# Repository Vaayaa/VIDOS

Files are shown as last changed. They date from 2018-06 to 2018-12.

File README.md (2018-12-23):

# VIDOS: Shader Based Video Synthesizer

VidBoi 1
## Overview

The VIDOS is a flexible Raspberry Pi based video synthesizer with OSC & CV inputs. At its core the device is built around shaders (video card code) and uses them to generate the visuals. VIDOS is a great way to interface the world of shader visuals with analog CV equipment such as Eurorack synthesizers or anything that happens to speak OSC.

Turn the knobs and explore or plug in your eurorack to create your own audio/visual universe!

Features:
- Runs on a Pi Zero
- Bipolar -5V to +5V CV inputs (Eurorack friendly!)
- Instantly Updating Shader Code (Live Coding Encouraged)
- OSC support
	- SHAPEFINDER Layout for Lemur & TouchOSC
- Open Source

Future Features:
- A Shader Specialized Eurorack Module
- MIDI Support

## OSC Control
Do you have one of those addicting pocket thingies?! Send packets with an app like TouchOSC or Lemur and control that shader! Send stuff to /vidos/0 ... 7 to control the corresponding CVs in the .frag

You can find Layouts in the /OSCLayouts Folder

## SHAPEFINDER 
The VIDOS comes with the SHAPEFINDER shader and Layout as a starting point for your own creations

This shader should start automatically when you run the main.out

## Writing Your Own Shaders

VIDOS is basically just a Raspberry Pi in a convenient package that is ready to be programmed.

### OVER WIFI using Sublime Text editor
1. Get Sublime here: https://www.sublimetext.com/
2. Use Sublime's SFTP package: https://wbond.net/sublime_packages/sftp
3. Follow the directions to edit /VIDOS/MyShader0.frag

## Learning About Shaders
Sound intimidating? It isn't! Shader Language is only slightly different from regular C based coding and is super fun!

Check out: https://thebookofshaders.com/ and you will be creating your own craziness in a matter of minutes.

When you're ready to take the show on the road and/or open your creations up to the world of modular synthesizers, take that same code and plug it into the VIDOS.

## Hardware CV Control
The hardware device comes with bipolar CV inputs that can be used to control each of these knobs with voltage rather than turning them by hand. When an input is present the position of the knob represents the center or 0V state of the parameter.

Pair VIDOS with an external LFO for slow morphing changes or patch in your modular sequencer for rhythmic frames in sync with the rest of your patch.

# Installation
## Software
0. flash rasbian
8. git clone https://github.com/teafella/VIDOS
59. ./install.sh

## Controlling the Shader (OSC SETUP)
1. Make sure your phone/pi are connected to thesame wifi network
2. Open A Lemur/TouchOSC layout on your phone
3. Point Lemur/TouchOSC at the pi (raspberrypi.local @ port 7000)

# OPTIONAL Setup
### Optional Installation (You probably already have this in default rasbian)
5. install wiringPI: http://wiringpi.com/download-and-install/

## Creating a Headless Raspberry Pi Zero (Ez Dev Ready Rig)

### Gear
- Pi Zero
- Micro USB cable
- Yurr Laptop

### Steps
1. OTG that thang:
		Guide: https://gist.github.com/gbaman/975e2db164b3ca2b51ae11e45e8fd40a 
2. Make sure you are sharing your wifi Connection: 
		OSX Guide: https://stevegrunwell.com/blog/raspberry-pi-zero-share-internet/
3. Log in with VNC: 
		Instructions: https://raspberrypi.stackexchange.com/questions/13986/how-to-have-remote-desktop-on-macbook-with-raspberry-pi

# Hardware (Dev Notes)

### MCP3008 Pinout
VMCP3008

## About The Creator
Ronald Sardarian is a musician, creative programmer and modular synthesizer enthusiast.

Check out [sardarian.wordpress.com](sardarian.wordpress.com) for more projects and [instagram.com/teafela/](instagram.com/teafela) for electronic music and visuals.

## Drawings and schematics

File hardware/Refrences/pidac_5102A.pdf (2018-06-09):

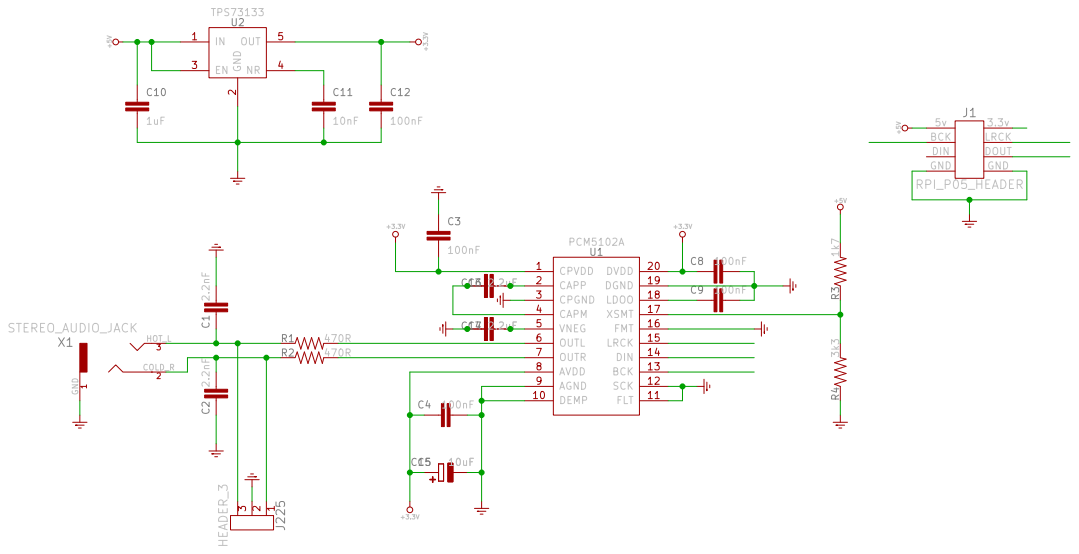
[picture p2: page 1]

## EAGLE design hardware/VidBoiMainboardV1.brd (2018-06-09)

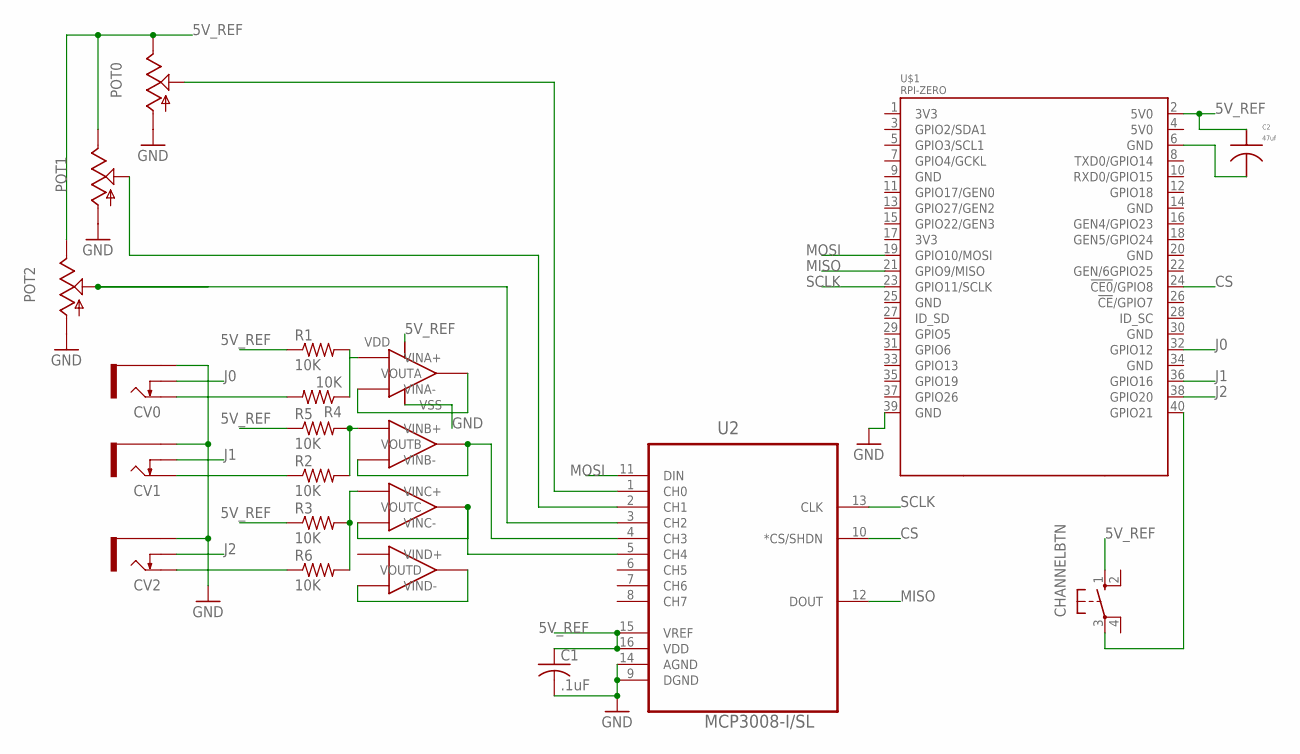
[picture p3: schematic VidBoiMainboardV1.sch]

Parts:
C1: .1uF; C025-024X044
C2: 47uf; CAP-PAN-FKS_V-DIM_C
CHANNELBTN: 10-XX; B3F-10XX
CV0, CV1, CV2: THONKICONNOLD; THONKICONN
POT0, POT1, POT2: 9MM_SNAP-IN_POT_; 9MM_SNAP-IN_POT
R1, R2, R3, R4, R5, R6: 10K; R0603
U2: MCP3008-I/SL; SOIC127P600X175-16N
U$1: RPI-ZERO; RASPBERRYPI_BASTELSTUBE_V13_RASPI_BOARD_B+_FULL
U$2: MCP6004SOIC-14; MCP6004ISL

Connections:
5V_REF: C1.1, C2.POS, CHANNELBTN.1 (S), POT0.3 (E), POT1.3 (E), POT2.3 (E), R1.1, R3.1, R5.1, U2.15 (VREF), U2.16 (VDD), U$1.2 (5V0), U$2.VDD
CS: U2.10 (*CS/SHDN), U$1.24 (!CE0!/GPIO8)
GND: C1.2, CV0.P$1_SLEEVE (SLEEVE), CV1.P$1_SLEEVE (SLEEVE), CV2.P$1_SLEEVE (SLEEVE), POT0.1 (A), POT1.1 (A), POT2.1 (A), U2.9 (DGND), U2.14 (AGND), U$1.39 (GND), U$2.VSS
GND@8: C2.NEG, U$1.6 (GND)
J0: CV0.P$2_SWITCH (SWITCH), U$1.32 (GPIO12)
J1: CV1.P$2_SWITCH (SWITCH), U$1.36 (GPIO16)
J2: CV2.P$2_SWITCH (SWITCH), U$1.38 (GPIO20)
MISO: U2.12 (DOUT), U$1.21 (GPIO9/MISO)
MOSI: U2.11 (DIN), U$1.19 (GPIO10/MOSI)
unnamed: CV0.P$3_TIP (TIP), R4.2
unnamed: R1.2, R4.1, U$2.VINA+
unnamed: CV1.P$3_TIP (TIP), R2.1
unnamed: U$2.VINA-, U$2.VOUTA
unnamed: POT0.2 (S), U2.1 (CH0)
unnamed: POT1.2 (S), U2.2 (CH1)
unnamed: POT2.2 (S), U2.3 (CH2)
unnamed: U2.4 (CH3), U$2.VINB-, U$2.VOUTB
unnamed: R3.2, R6.2, U$2.VINC+
unnamed: U2.5 (CH4), U$2.VINC-, U$2.VOUTC
unnamed: U$2.VIND-, U$2.VOUTD
unnamed: CV2.P$3_TIP (TIP), R6.1
unnamed: R2.2, R5.2, U$2.VINB+
unnamed: CHANNELBTN.3, U$1.40 (GPIO21)
SCLK: U2.13 (CLK), U$1.23 (GPIO11/SCLK)

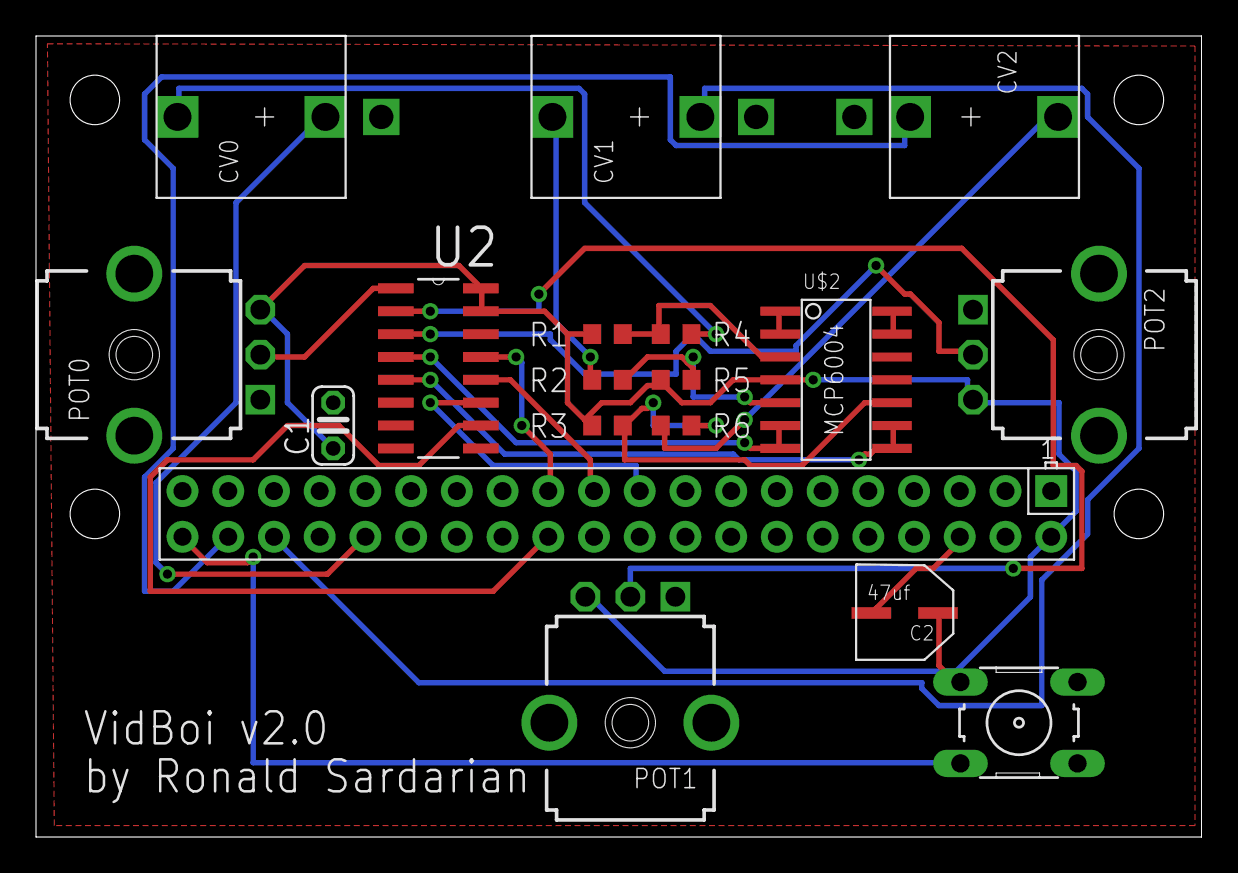
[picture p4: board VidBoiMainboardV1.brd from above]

Board: 2 copper layers, 64.8 x 44.5 mm, 18 parts (0 on the bottom side), 24 nets.

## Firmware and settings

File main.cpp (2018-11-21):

#include <stdio.h>
#include <fcntl.h>
#include <stdlib.h>
#include <string.h>
#include <math.h>
#include <assert.h>
#include <unistd.h>
#include <string>
#include <iostream>
#include <fstream>
#include <thread>

#include <linux/input.h>


//gl Includes
#include "bcm_host.h"
#include "GLES2/gl2.h"
#include "GLES2/gl2ext.h"
#include "EGL/egl.h"
#include "EGL/eglext.h"

//my includes
#include "src/util.cpp"
#include "lib/SOIL.h"
#include "src/input.h"
#include "src/audio.h"
#include "src/fileWatcher.h"
#include "src/Shader.h"

//Global defines
#include <time.h>
#define NUM_SCENES 1
#define IMAGE_SIZE 128

#define IN_TEX_NAME "/images/pusheen.png"
#define CONTEXT_DIV 2

clock_t begin = clock();

bool programRunning = true;

Input* inputs;
Audio* audio;
FileWatcher* watcher;

bool loadNewScene = false;
float lastButtonState = 0;
float buttonState = 0;

typedef struct
{
  uint32_t screen_width;
  uint32_t screen_height;
// OpenGL|ES objects
  EGLDisplay display;
  EGLSurface surface;
  EGLContext context;

  GLuint verbose;
  GLint inputValY = 0;
  GLint inputValX = 0;
  GLint sceneIndex = 1;
  std::vector<GLushort> inputCVList;
  GLfloat inputCV0 = 0.0;
  GLfloat inputCV1 = 0.0;
  GLfloat inputCV2 = 0.;
  GLfloat inputCV3 = 0.;
  GLfloat inputCV4 = 0.;
  GLfloat inputCV5 = 0.;
  GLfloat inputCV6 = 0.0;
  GLfloat inputCV7 = 0.0;

  GLint switch0 = 0;
  GLint switch1 = 0;
  GLint switch2 = 0;

  GLfloat inputFFT[4] = {0.0, 0.0, 0.0, 0.0};
  GLuint vshader;
  GLuint fshader;
  GLuint mshader;
  GLuint program;
  GLuint framebuffer;
  GLuint tex[5];
  GLuint buf;

  //create pixel buffer pointer (for passing color into audio engine)
  GLubyte* pixels;
  int pixelsSize;

  //audio to video vars
  std::vector<float> buffer1;
  std::vector<float> buffer2;

  unsigned char* inputImageTexBuf;
  int buf_height, buf_width;
// my shader attribs
  GLuint unif_color, attr_vertex, unif_scale, unif_offset, unif_tex, unif_centre, unif_resolution, unif_texCV, unif_texFB, unif_texIN, unif_cv0, unif_cv1, unif_cv2,unif_cv3,unif_cv4,unif_cv5, unif_cv6, unif_cv7, unif_fft, unif_sw0, unif_sw1, unif_sw2;
  GLuint unif_inputVal, unif_sceneIndex;

  GLuint unif_time;
} CUBE_STATE_T;

static CUBE_STATE_T _state, *state = &_state;
int e;
#define check() e = glGetError(); if(e != 0) std::cout << "GL ERROR "<< e << " on line: "<< __LINE__ <<std::endl; assert(glGetError() == 0); 

static void checkFramebuffer() {
  GLenum ret = glCheckFramebufferStatus(GL_FRAMEBUFFER);
  if (ret != GL_FRAMEBUFFER_COMPLETE) {
    std::cout << " Framebuffer issue " << ret <<   std::endl;
    if ( ret == GL_FRAMEBUFFER_INCOMPLETE_ATTACHMENT) {
      std::cout << "GL_FRAMEBUFFER_INCOMPLETE_ATTACHMENT" << std::endl;
    }
  }
}

static bool showlog(GLint shader)
{
  // Prints the compile log for a shader
  char log[1024] = {0};
  glGetShaderInfoLog(shader, sizeof log, NULL, log);
  printf("\n%d:shader:\n%s\n", shader, log);
  if(log != 0){
    return true;
  }
  return false;

}

static void showprogramlog(GLint shader)
{
  // Prints the information log for a program object
  char log[1024];
  glGetProgramInfoLog(shader, sizeof log, NULL, log);
  printf("\n%d:program:\n%s\n", shader, log);
}

static std::string getExecutablePath() {
  char buf[255] = "";
  readlink("/proc/self/exe", buf, sizeof(buf) );
  std::string path = std::string(buf);
  int position = path.rfind ('/');
  path = path.substr(0, position) + "/";
  return path;
}




/***********************************************************
 * Name: init_ogl
 *
 * Arguments:
 *       CUBE_STATE_T *state - holds OGLES model info
 *
 * Description: Sets the display, OpenGL|ES context and screen stuff
 *
 * Returns: void
 *
 ***********************************************************/
static void init_ogl(CUBE_STATE_T *state)
{
  int32_t success = 0;
  EGLBoolean result;
  EGLint num_config;

  static EGL_DISPMANX_WINDOW_T nativewindow;

  DISPMANX_ELEMENT_HANDLE_T dispman_element;
  DISPMANX_DISPLAY_HANDLE_T dispman_display;
  DISPMANX_UPDATE_HANDLE_T dispman_update;
  VC_RECT_T dst_rect;
  VC_RECT_T src_rect;

  static const EGLint attribute_list[] =
  {
    EGL_RED_SIZE, 8,
    EGL_GREEN_SIZE, 8,
    EGL_BLUE_SIZE, 8,
    EGL_ALPHA_SIZE, 8,
    EGL_SURFACE_TYPE, EGL_WINDOW_BIT,
    EGL_NONE
  };

  static const EGLint context_attributes[] =
  {
    EGL_CONTEXT_CLIENT_VERSION, 2,
    EGL_NONE
  };
  EGLConfig config;

  // get an EGL display connection
  state->display = eglGetDisplay(EGL_DEFAULT_DISPLAY);
  assert(state->display != EGL_NO_DISPLAY);
  check();

  // initialize the EGL display connection
  result = eglInitialize(state->display, NULL, NULL);
  assert(EGL_FALSE != result);
  check();

  // get an appropriate EGL frame buffer configuration
  result = eglChooseConfig(state->display, attribute_list, &config, 1, &num_config);
  assert(EGL_FALSE != result);
  check();

  // get an appropriate EGL frame buffer configuration
  result = eglBindAPI(EGL_OPENGL_ES_API);
  assert(EGL_FALSE != result);
  check();

  // create an EGL rendering context
  state->context = eglCreateContext(state->display, config, EGL_NO_CONTEXT, context_attributes);
  assert(state->context != EGL_NO_CONTEXT);
  check();

  // create an EGL window surface
  success = graphics_get_display_size(0 /* LCD */, &state->screen_width, &state->screen_height);
  assert( success >= 0 );

  // state->screen_width = 640;
  // state->screen_height = 480;

  dst_rect.x = 0;
  dst_rect.y = 0;
  dst_rect.width = state->screen_width ;
  dst_rect.height = state->screen_height;

  src_rect.x = 0;
  src_rect.y = 0;
  src_rect.width = state->screen_width / CONTEXT_DIV << 16;
  src_rect.height =  state->screen_height / CONTEXT_DIV << 16;

  dispman_display = vc_dispmanx_display_open( 0 /* LCD */);
  dispman_update = vc_dispmanx_update_start( 0 );

  dispman_element = vc_dispmanx_element_add ( dispman_update, dispman_display,
                    0/*layer*/, &dst_rect, 0/*src*/,
                    &src_rect, DISPMANX_PROTECTION_NONE, 0 /*alpha*/, 0/*clamp*/,  (DISPMANX_TRANSFORM_T)0/*transform*/);


  nativewindow.element = dispman_element;
  nativewindow.width = state->screen_width;
  nativewindow.height = state->screen_height;
  vc_dispmanx_update_submit_sync( dispman_update );

  check();

  state->surface = eglCreateWindowSurface( state->display, config, &nativewindow, NULL );
  assert(state->surface != EGL_NO_SURFACE);
  check();

  // connect the context to the surface
  result = eglMakeCurrent(state->display, state->surface, state->surface, state->context);
  assert(EGL_FALSE != result);
  check();

  // Set background color and clear buffers
  glClearColor(0.15f, 0.25f, 0.35f, 1.0f);
  glClear( GL_COLOR_BUFFER_BIT );
  //disable depth Buffer
  //glDepthMask(false);

  //set 
  eglSwapInterval( state->display, 2.1);

  check();

  state->pixelsSize = state->screen_width * state->screen_height * 3;
  state->pixels = new GLubyte[state->pixelsSize];

  std::cout<< "GL VERSION: " << glGetString(GL_SHADING_LANGUAGE_VERSION) << std::endl;
}

std::string readFile(const char *filePath) {

  std::string line = "";
  std::ifstream in(filePath);
  if (!in.is_open()) {
    std::cerr << "Could not read file " << filePath << ". File does not exist." << std::endl;
    return "";
  }
  std::string content((std::istreambuf_iterator<char>(in)),
                      std::istreambuf_iterator<char>());

  in.close();
  return content;
}


static void load_tex_images(CUBE_STATE_T *state)
{
  SOIL_free_image_data(state->inputImageTexBuf);
  //SOIL LOADER
  state->inputImageTexBuf = SOIL_load_image(( getExecutablePath() + std::string(IN_TEX_NAME)).c_str(), &state->buf_width, &state->buf_height, 0, SOIL_LOAD_RGB);

  if ( 0 == state->inputImageTexBuf)
  {
    printf( "SOIL loading error: '%s'\n", SOIL_last_result() );
  }

}

static void init_shaders( bool firstrun = true)
{
  // Points for a screen size poly to draw the shader on
  static const GLfloat vertex_data[] = {
    -1.0, -1.0, 1.0, 1.0,
    1.0, -1.0, 1.0, 1.0,
    1.0, 1.0, 1.0, 1.0,
    -1.0, 1.0, 1.0, 1.0
  };
  //initialize cv input texture
  //state->inputCVList = std::vector<GLushort>(CV_LIST_SIZE + sqrt(CV_LIST_SIZE) + 1 , 0);
  state->inputCVList = std::vector<GLushort>(RECORD_BUFFER + sqrt(RECORD_BUFFER) + 1 , 0);

  //TODO: Automatically read files in Shaders/ directory
  //load up the shader files
  std::string vertShaderStr = readFile((getExecutablePath() + "vshader.vert").c_str());
  std::string fragShaderStr = readFile((getExecutablePath() + "/Shaders/myShader" + std::to_string(state->sceneIndex) + ".frag").c_str());
  const char *vertShaderSrc = vertShaderStr.c_str();
  const char *fragShaderSrc = fragShaderStr.c_str();

  //basic vert shader
  const GLchar *vshader_source = vertShaderSrc;
  //my custom fragment shader
  const GLchar *fshader_source = fragShaderSrc;

  //set verbose to always be true ( print out shader errors)
  state->verbose = true;

  state->vshader = glCreateShader(GL_VERTEX_SHADER);
  glShaderSource(state->vshader, 1, &vshader_source, 0);
  glCompileShader(state->vshader);

  if (state->verbose && !showlog(state->fshader)){
    return;
  }
  check();

  state->fshader = glCreateShader(GL_FRAGMENT_SHADER);
  glShaderSource(state->fshader, 1, &fshader_source, 0);
  glCompileShader(state->fshader);
  check();

  if (state->verbose && !showlog(state->fshader)){
    return;
  }


  // custom shader attach
  state->program = glCreateProgram();
  glAttachShader(state->program, state->vshader);
  glAttachShader(state->program, state->fshader);
  glLinkProgram(state->program);
  glDetachShader(state->program, state->vshader);
  glDetachShader(state->program, state->fshader);
  glDeleteShader(state->vshader);
  glDeleteShader(state->fshader);

  check();

  if (state->verbose)
    showprogramlog(state->program);

  //set up input uniforms

  state->attr_vertex = glGetAttribLocation(state->program, "vertex");
  state->unif_color  = glGetUniformLocation(state->program, "color");
  state->unif_scale  = glGetUniformLocation(state->program, "scale");
  state->unif_offset = glGetUniformLocation(state->program, "offset");
  state->unif_texIN    = glGetUniformLocation(state->program, "texIN");
  state->unif_texCV    = glGetUniformLocation(state->program, "texCV");
  state->unif_texFB    = glGetUniformLocation(state->program, "texFB");
  state->unif_resolution   = glGetUniformLocation(state->program, "resolution");
  state->unif_centre = glGetUniformLocation(state->program, "centre");
  state->unif_time = glGetUniformLocation(state->program, "time");
  state->unif_inputVal = glGetUniformLocation(state->program, "inputVal");
  state->unif_sceneIndex = glGetUniformLocation(state->program, "sceneIndex");
  state->unif_cv0 = glGetUniformLocation(state->program, "cv0");
  state->unif_cv1 = glGetUniformLocation(state->program, "cv1");
  state->unif_cv2 = glGetUniformLocation(state->program, "cv2");
  state->unif_cv3 = glGetUniformLocation(state->program, "cv3");
  state->unif_cv4 = glGetUniformLocation(state->program, "cv4");
  state->unif_cv5 = glGetUniformLocation(state->program, "cv5");
  state->unif_cv6 = glGetUniformLocation(state->program, "cv6");
  state->unif_cv7 = glGetUniformLocation(state->program, "cv7");
  state->unif_fft = glGetUniformLocation(state->program, "fft");

  //switches
  state->unif_sw0 = glGetUniformLocation(state->program, "sw0");
  state->unif_sw1 = glGetUniformLocation(state->program, "sw1");
  state->unif_sw2 = glGetUniformLocation(state->program, "sw2");



  glClearColor ( 0.0, 1.0, 1.0, 1.0 );
  if (!firstrun) {
    glDeleteBuffers(1, &state->buf);
  }
  glGenBuffers(1, &state->buf);

  check();

  // Prepare a texture image
  if (!firstrun) {
    glDeleteTextures(3,  &state->tex[0]);
  }
  glActiveTexture(GL_TEXTURE0);
  glGenTextures(3, &state->tex[0]);
  check();
  checkFramebuffer();
  //setup drawing texture ( bound to main fb later)
  glBindTexture(GL_TEXTURE_2D, state->tex[0]);
  check();

  //try to set SD here: 640×480
  //glTexImage2D(GL_TEXTURE_2D, 0, GL_RGB, state->screen_width  , state->screen_height , 0, GL_RGB, GL_UNSIGNED_SHORT_5_6_5, 0);
  int contextW = 640;
  int contextH = 480;
  glTexImage2D(GL_TEXTURE_2D, 0, GL_RGB, state->screen_width /CONTEXT_DIV,  state->screen_height /CONTEXT_DIV, 0, GL_RGB, GL_UNSIGNED_SHORT_5_6_5, 0);
  check();
  glTexParameterf(GL_TEXTURE_2D, GL_TEXTURE_MIN_FILTER, GL_LINEAR);
  glTexParameterf(GL_TEXTURE_2D, GL_TEXTURE_MAG_FILTER, GL_LINEAR);
  check();

  // setup tex index 1 (used for CV input)
  glActiveTexture(GL_TEXTURE0 + 1);
  glBindTexture(GL_TEXTURE_2D, state->tex[1]);

  glTexImage2D(GL_TEXTURE_2D, 0, GL_RGB, 3 , 2, 0,
               GL_RGB, GL_UNSIGNED_SHORT_5_6_5, &state->inputCVList[0]);
  check();
  glTexParameterf(GL_TEXTURE_2D, GL_TEXTURE_MIN_FILTER, (GLfloat)GL_LINEAR);
  glTexParameterf(GL_TEXTURE_2D, GL_TEXTURE_MAG_FILTER, (GLfloat)GL_LINEAR);
  check();

  //Unit 2: input tex
  load_tex_images(state);
  glActiveTexture(GL_TEXTURE0 + 2);
  glBindTexture(GL_TEXTURE_2D, state->tex[2]);
  glTexImage2D(GL_TEXTURE_2D, 0, GL_RGB, state->buf_width, state->buf_height, 0,
               GL_RGB, GL_UNSIGNED_BYTE, state->inputImageTexBuf);
  glTexParameterf(GL_TEXTURE_2D, GL_TEXTURE_MIN_FILTER, (GLfloat)GL_LINEAR);
  glTexParameterf(GL_TEXTURE_2D, GL_TEXTURE_MAG_FILTER, (GLfloat)GL_LINEAR);
  check();

  //changed to feedback texture (doesnt work...)
  // glActiveTexture(GL_TEXTURE0 + 2);
  // glBindTexture(GL_TEXTURE_2D, state->tex[2]);
  // glTexImage2D(GL_TEXTURE_2D, 0, GL_RGB, 3 , 2, 0,
  //              GL_RGB, GL_UNSIGNED_SHORT_5_6_5, &state->inputCVList[0]);
  // check();
  // glTexParameterf(GL_TEXTURE_2D, GL_TEXTURE_MIN_FILTER, (GLfloat)GL_LINEAR);
  // glTexParameterf(GL_TEXTURE_2D, GL_TEXTURE_MAG_FILTER, (GLfloat)GL_LINEAR);
  // glTexParameteri(GL_TEXTURE_2D, GL_TEXTURE_WRAP_S, GL_REPEAT);
  // glTexParameteri(GL_TEXTURE_2D, GL_TEXTURE_WRAP_T, GL_REPEAT);
  // check();



  // Prepare a framebuffer for rendering
  if (!firstrun) {
    glDeleteFramebuffers(1, &state->framebuffer);
  }

  glGenFramebuffers(1, &state->framebuffer);
  check();

  glBindFramebuffer(GL_FRAMEBUFFER, state->framebuffer);
  check();

  glFramebufferTexture2D(GL_FRAMEBUFFER, GL_COLOR_ATTACHMENT0, GL_TEXTURE_2D, state->tex[0], 0);
  check();
  
  checkFramebuffer();
  if(firstrun){
    // Prepare viewport
    glViewport ( 0, 0, state->screen_width, state->screen_height );

    check();
  }
    // Upload vertex data to a buffer
    glBindBuffer(GL_ARRAY_BUFFER, state->buf);
    glBufferData(GL_ARRAY_BUFFER, sizeof(vertex_data),
                 vertex_data, GL_STATIC_DRAW);
    glVertexAttribPointer(state->attr_vertex, 4, GL_FLOAT, 0, 16, 0);
    glEnableVertexAttribArray(state->attr_vertex);
    check();
}

static void restart_shaders(){
  loadNewScene = true;
}
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
int main ()
{

  int terminate = 0;
  GLfloat cx, cy;
  bcm_host_init();

  // Clear application state
  memset( state, 0, sizeof( *state ) );

  //Start Inputs
  inputs = new Input();

  //Start Audio Engine
  // audio = new Audio(inputs);
  // std::cout << "Audio Started" << std::endl;

  watcher = new FileWatcher(getExecutablePath() + "Shaders", &restart_shaders);
  

  // Start OGLES
  init_ogl(state);
  init_shaders();
  cx = state->screen_width / 2;
  cy = state->screen_height / 2;

  setupKeyboard();
  inputs->addButtonCallback(&onButton);
  while (!terminate)
  {
    clock_t frameBegin = clock();

    if (!readKeyboard()) {
      destroyShader();
      terminate = true;
    }
    else if (loadNewScene  == true) {
      destroyShader();
      init_ogl(state);
      init_shaders(false);
      loadNewScene = false;
    }
    else {
      draw_triangles(state, cx, cy, 0.003);
    }

    if (SHOW_FRAMETIME) {
      clock_t frameEnd = clock();
      double elapsed_secs = double(frameEnd - frameBegin) / CLOCKS_PER_SEC;
      std::cout << "Frame Time: " << elapsed_secs << std::endl;
    }

    //if(elapsed_secs < .03 ){ sleep(0.03 - elapsed_secs); }

  }


  fflush(stdout);
  fprintf(stderr, "%s.\n", strerror(errno));

  delete(inputs);
  // delete(audio);
  delete(state->pixels);


  return 0;
}

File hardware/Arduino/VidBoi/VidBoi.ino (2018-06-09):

// FFT library options
// See http://wiki.openmusiclabs.com/wiki/Defines 
#define FFT_N 16 
#define WINDOW 0
#define OCTAVE 1
#define OCT_NORM 0
#include <FFT.h>

#define SAMPLE_PERIOD_MICROSECONDS 250

bool DEBUG = true;

int numInputs = 3;
const byte cvIn[] = {A2, A1, A0};
int numPots = 3;
const byte potIn[]= {A5, A4, A3};
const byte audioPin = A1;
const byte buttonPin =  9;

void setup() {
  analogReference(DEFAULT);
  Serial.begin(115200);
  
  // Setup CV inputs
  pinMode(cvIn[0], INPUT);
  pinMode(cvIn[1], INPUT);
  pinMode(cvIn[2], INPUT);
  pinMode(buttonPin, INPUT);

}

/* Function: getSamples
 * --------------------
 * Populates every other element of an array with FFT_N samples, sampled at
 * 1000/SAMPLE_PERIOD_MICROSECONDS kHz. Takes about 6.7ms to run.
 */
void getSamples(int samples[FFT_N*2]) {
  unsigned long next_sample_time = micros();
  for (byte i = 0; i < FFT_N*2; i+=2) {
    while (micros() < next_sample_time); // wait till next sample time
    samples[i] = analogRead(audioPin) - 512;
    samples[i+1] = 0;
    next_sample_time += SAMPLE_PERIOD_MICROSECONDS;
  }
}



int last[] = {0,0,0}; // needs global scope


bool on = false;
void sampleCV(){

  int sample, in, scaled;
  for(int x = 0; x < numInputs; ++x){
    //read and smooth
    in = analogRead(cvIn[x]);
    sample = smooth(in, last[x]);

    if(sample != -1 && sample != last[x]){
      //save raw value for next smoothing comparison
      last[x] = sample;

      
      //output value using serial ( rescale val/1023.0 for 0. to 1. on the other end)
      String out = String(x) + String(" ");
      Serial.println(out + sample);

    }
    else{
      //work around for 1023 pull up readout ( no jack which should be 0 )
      if( in == 1023 && last[x] != 1023){
          last[x] = 1023;
          String out = String(x) + String(" ");
          Serial.println(out + String("0"));
      }
    }
  }
}

int lastPot[] = {0,0,0}; // needs global scope

void samplePot(){
  int sample,in, scaled;
  for( int x = 0; x < numPots; ++x){
    in = analogRead(potIn[x]);
    sample = smooth(in, lastPot[x]);
    if(sample != -1  && sample != lastPot[x]){
      //save raw value for next smoothing comparison
      lastPot[x] = sample;

      //output value using serial ( rescale val/1023.0 for 0. to 1. on the other end)
      String out = String(x + 10) + String(" ");
      Serial.println(out + sample );
    } 
   }
}

int buttonState;             // the current reading from the input pin
int lastButtonState = LOW;   // the previous reading from the input pin
unsigned long lastDebounceTime = 0;  // the last time the output pin was toggled
unsigned long debounceDelay = 10;    // the debounce time; increase if the output flickers

void sampleButton(){
  // read the state of the switch into a local variable:
  int reading = digitalRead(buttonPin);

  if (reading != lastButtonState) {
    // reset the debouncing timer
    lastDebounceTime = millis();
  }

  if ((millis() - lastDebounceTime) > debounceDelay) {
    // whatever the reading is at, it's been there for longer than the debounce
    // delay, so take it as the actual current state:

    // if the button state has changed:
    if (reading != buttonState) {
      buttonState = reading;

      //send button state over serial ( message number 30 )
      if(buttonState == HIGH){
         Serial.println( "30 1");
      }
      else{
         Serial.println( "30 0");
      }
    }
  }

  lastButtonState = reading;
}



int smooth(int in, int PotPrevVal){ 
    int margin = PotPrevVal * .00001; //  get 2% of the raw value.  Tune for lowest non-jitter value.
    /*
     * Next we add (or subtract...) the 'standard' fixed value to the previous reading. (PotPrevVal needs to be declared outside the function so it persists.)
     * Here's the twist: Since the jitter seems to be worse at high raw vals, we also add/subtract the 2% of total raw. Insignificantat on low 
     * raw vals, but enough to remove the jitter at raw >900 without wrecking linearity or adding 'lag', or slowing down the loop, etc.
     */
    if (in > PotPrevVal + (4 + margin) || in < PotPrevVal - (5 + margin)) { // a 'real' change in value? Tune the two numeric values for best results
      //average last 2 values ofr smoothing
      in = (PotPrevVal + in) / 2.0;
      //PotPrevVal = in; // store valid raw val  for next comparison
      return in;
    }  
    return -1;  
}

//sends FFT data over serial, 255 staring int means 4 ints/bins of fft follow
void sendFFT( byte bins[LOG_N] ){
    Serial.println(String(100) + ' ' + bins[0]);
    Serial.println(String(101) + ' ' + bins[1]);
    Serial.println(String(102) +' ' + bins[2]);
    Serial.println(String(103) +' ' + bins[3]);
}


void loop() {
  // put your main code here, to run repeatedly:
  sampleButton();
  sampleCV();
  samplePot();

  //FFT 
  //getSamples(fft_input);
//  fft_reorder();
//  fft_run();
//  fft_mag_octave();

//  sendFFT(fft_oct_out);
  

}

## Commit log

2018-05-02 Update README.md
    Note about wiring PI installation
2018-06-09 Recovered/Correct CV arrays
    [VidBoi.fzz]
2018-06-09 Added V1 Board/Schematic
    [VidBoiMainboardV1.brd, VidBoiMainboardV1.sch]
2018-06-09 Added refrence schematic for DAC
2018-08-04 Pitch controlls / Basic FM OSCs
2018-10-27 Merging OSC Bugfixing :/
    [input.cpp]
2018-10-29 feedback/SD context/fixed switches vidos/100+ are switch controlls
    [input.cpp, main.cpp]
